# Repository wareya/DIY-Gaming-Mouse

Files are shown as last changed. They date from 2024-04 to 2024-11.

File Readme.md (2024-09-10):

# DIY Gaming Mouse

Video about why and how I made this, and what the various iterations were like: https://www.youtube.com/watch?v=h-Cdl4Vq9H4

This repository contains the code, schematic, PCB layout, and 3d model for a completely DIY gaming mouse, all designed around a Pixart PMW3360 sensor.

The firmware for this mouse uses a special debouncing algorithm that completely eliminates chatter without adding ANY latency, and eliminates bounce better than commercial mice do. Random double-clicks be gone!

None of the companies that make gaming mouse sensors sell them to consumers, including Pixart, so the sensor needs to be salvaged (or bought from a scalper, or a small business that specializes in reselling them).

<table>
  <tr>
    <td>
      
    </td>
    <td>
      
    </td>
  </tr>
  <tr>
    <td>
      opened mouse
    </td>
    <td>
      assembled mouse
    </td>
  </tr>
</table>

(The shell has a top, too, but it's turned off in this picture so you can see the PCB.)

## Features

- True zero-latency button debouncing with no glitching
- Buttons that will not develop double-clicking problems after only a few months
- Low-latency motion tracking (no smoothing)
- Completely open source (Apache 2.0 license)
- Even the hardware is open source! (except the processor and sensor)
- Ultra light-weight shell and assembly (55g in total)
- Fingertip-grip shell shape
- Extra middle mouse button
- - the button that normally controls DPI on other mice is mapped to M3
- PCB exposes extra unused pins from the rp2040 as test pads for hardware/firmware modding fun; attach your own sensors! or LEDs! whatever you want!
- Full 1000hz tracking

TODO:

- Configurable DPI (currently hardcoded at 1200)
- - To change it in the firmware code, edit the `spi_write(REG_CONFIG1, 11); // 1200 dpi` line, replacing 11 with your dpi divided by 100 minus 1, e.g. 7 for 800 dpi, 3 for 400, 15 for 1600, etc
- rebinding, macros, etc
- - can already be hardcoded atm if you're skilled at programming
- "fun" optional features like WMO-style diagonal jaggy removal or optional in-firmware acceleration, anti-smoothing (prediction), angle snapping, cinematic smoothing, etc

## Required skills

You need to be familiar with, or be able to learn quickly:

- 3d printing
- how to use a "slicer" (e.g. Cura) to convert stl models to gcode (what your 3d printer uses)
- repeatedly making test prints
- how to clean up 3d prints and remove support material from fragile prints
- basic firmware code debugging skills
- the ability to read embedded C/C++ code
- the Arduino IDE (I use 2.x, not 1.x)
- desoldering (with a hot air rework station)
- soldering (with a soldering iron)
- soldering bodge wires to existing pieces of hardware without creating solder bridges (for SROM extraction)
- comfort using a hot air rework station to soften and fix misshapen parts on 3d printed objects if they print improperly
- the ability to do all of the above without wasting tons of money or burning your home down
- familiarity with PCB printing companies and PCB assembly manufacturers (JLCPCB, PCBWay, etc)
- patience

If you cannot do all of the above, you should have someone else build this project for you, rather than building it for yourself. Or, at the very least, I can't give you support if you don't have the skills needed to make this; I'm just some random guy.

You also need:

- access to a 3d printer that you can repeatedly print test prints on until they come out right
- a hot air rework station with temperature and air flow rate control
- a soldering iron with temperature control
- hot glue device (for securing the USB cable, nothing else)
- various small tools like screwdrivers, tweezers, cleanup blades / deburring tools, etc. for various parts of the building process

## Instructions

### 3D printing the shell

This assumes you're using a filament printer. Resin printers might work too, but I have never used one.

I print with PLA filament.

Print each of the STL files in the "Case Model" directory in their natural (not default!) orientations. To repeat, some of the models have to be rotated; they're saved in the orientation they have in the mouse, not the orientation they need to have on the 3d printer's build plate.

You need to convert the stl files to gcode yourself and run various test prints because each 3d printer and filament has different requirements for layer thickness, support cutoff angle, printing speed, z seam alignment placement, etc.

Cura will complain about certain pieces (like the shell bottom) not being "water tight", but it's wrong; the watertightness check doesn't handle multiple overlapping solids properly. The models will still slice correctly and without glitches.

The thumb pieces must be rotated into the orientation where they do not need any supports. This means the small part of the thumb piece is facing up, and the long part of the switch clamp section is on the bottom.

The scroll wheel must be rotated so that the thick cylinder part is on the bottom and the thin pin part is on the top. It must be printed with supports; any type of support is fine. It should be printed at 100% speed or lower, not higher, until it gets to the pin, at which point you MUST reduce the printing speed as low as you can tolerate. On my printer, a Sovol SV06, I had to turn it down to 25% speed. If your printer doesn't allow you to change the speed mid-print, you have to print at the low speed for the entire print. This is important; you have to print it slowly, because otherwise, the pin will be misaligned with itself and the scroll wheel will be off-balance and hit the middle mouse button switch with different pressures depending on where it is in its spin cycle.

Print the scroll wheel brace as-is.

Print the shell bottom as-is. However, if you have a heated printbed or chamber, you need to wait for it to completely cool before removing it. If you remove the print while it's warm, the bottom will bend and the mouse won't sit flat. Even with mouse feet, the sensor will be at the wrong height if the bottom is bent.

Print the shell top with tree supports and a support cutoff angle between 60 and 70 degrees. Do not use "standard"/traditional/grid supports; they will be too difficult to remove, and you will probably damage the print trying to remove them. On my printer, a Sovol SV06, 67 degrees was just right. If you have poor print quality, you might need to reduce the cutoff angle down to something silly like 50 degrees. If you have to go below 50 degrees, get a better printer, or make sure you're using the right filament at the right temperature, etc.

Once the shell top is printed, you need to use a deburring tool (or other hard, sharp metal implement) to remove a small amount of material from a certain curved edge along the seam where it meets the shell bottom, on the right side of the shell (with the button pieces away from you and the "butt" part towards you). The shell will fit together without removing a small amount of material from this part of the shell top, but it'll be misaligned by around a quarter of a millimeter and the right click won't quite work right. This material has to be removed because it sags during printing, and it sags during printing because of how support bridging works; the 3d model itself is correct.

You should print each part one-by-one and check for errors each time.

The final result will be somewhat rough and rugged, but it's a functional mouse shell.

### SROM preparation

Note: The SROM is optional, but highly recommended because it contains sensor firmware bugfixes. If you can't get it, comment out the call to `srom_upload();` in `pmw3360_boot()`, and then rename the `.h` file inclusion to `#include "srom_dummy_blank.h"`, but be warned that your mouse might experience glitchy behavior like "spinout" or have generally poor tracking. For example, while writing this and testing the firmware without an SROM, I click-and-dragged a title bar on a window, and then the mouse cursor teleported 300~400 pixels to the right for no reason.

The SROM needs to be captured from an existing mouse because it's copyrighted. Give it the name `srom_3360_0x03.h`, `srom_3360_0x04.h`, or `srom_3360_0x05.h`, depending on what version it is. I poked around github and found other projects using the 3360 SROM, and this seems to be the way they decided to name their SROM header files, so I'm copying the filename from them.

Once you have the SROM, edit the `#include "srom_3360_0x05.h"` line in `3360_Mouse_pico.ino` to point to the file for your SROM.

The below is instructions on how to capture the SROM from a commercial mouse.

Capture the SROM from a commercial 3360 mouse with this code, and a standalone raspberry pi pico (not this mouse's custom PCB): https://gist.github.com/wareya/0dc3498bd80be93c47b6f79aa9164321

Note: the above SROM capturing code requires you to use the "arduino-pico" board type in the Arduino IDE. But the firmware in this repostory requires you to use the "mbed OS" rp2040 board type.

Use a breadboard to make a ripping setup equivalent to that depicted in the following image:

EspAlvz

And this post: https://github.com/wareya/DIY-Gaming-Mouse/issues/6#issuecomment-2340009477

Be very careful not to create any solder bridges between any of the pins on the 3360.

Reconnect the mouse so that it reboots and sends the SROM to the sensor again.

The output should be exactly 4094 bytes long, and the second byte should be 0x03, 0x04, or 0x05 (different versions).

Repeat the capturing process until you get the same SROM several times, just to make sure that it captured properly. To capture the SROM again, you need to reboot the mouse. This can be plugging it in to your computer again, or disconnecting and reconnecting its USB power wire, or any safe method you prefer.

The MD5 checksums of the versions of the SROM that I know about are:

```
0x03 - C64F2BDA742DD1623D6A5DC869FC5E60
0x04 - 0BCB410858FF21D091DDC497D19BC943
0x05 - 337254C54AD82C689D4B9A58D06A3CF6
```

If you have an SROM with a different version number, it might not work with this firmware. It might, but it also might not. I can't provide support for other SROM versions.

After capturing the SROM data, save it in a formatted .h file formatted as such:

```c

#define SROM_LENGTH (4094)

const uint8_t PROGMEM srom[SROM_LENGTH] =
{
0x01,
0x<version number>,
// ...
// etc
};
```

I cannot distribute the SROM in this repository, because it's copyrighted proprietary code.

Disclaimer: The above steps do not bypass any copy protection, no encryption is being broken, and copyright law is not being violated by making your own backup copy of the sensor's SROM and using it on your own device. This is fully legal in reasonable countries (like the US).

### PMW 3360 sensor salvage

The Pixart PMW3360 is not sold commercially to hobbyists or small repair shops; to get one, you have to either buy an expensive breakout board, buy it from scalpers on aliexpress (or similar), or salvage it from an existing commercial mouse. This project assumes that you're salvaging it from an existing commercial mouse, after capturing the SROM from that mouse.

You need a hot air rework station, NOT a soldering iron, to desolder and salvage the 3360 safely. If you try to use a soldering iron, even with desoldering wick and/or a desoldering pump, you are VERY likely to fail to salvage it, damaging the pins or sensor internals in the process. The 3360 is somewhat sensitive to high temperatures, so you can only heat it up for a fairly short amount of time, and desoldering the ground pin with a soldering iron will get the sensor hot enough that it might start to damage it.

The 3360 sensor's lens is usually directly mounted to the sensor by melting its clear mounting pins down onto the top of the sensor's IC package.

Take the commercial mouse's PCB, scrape off (don't break off) the top melted part of the lens's mounting posts. Then, being careful not to damage anything, remove the lens from the sensor and PCB and put it somewhere safe.

Now, put the commercial mouse's PCB upside down on a non-flammable surface, in a workspace free of any flammable material. I cannot be held responsible if you start a fire in an unsafe workspace. You have been warned!

Before continuing, you might want to cover the bottom of the sensor with paper and/or tape to prevent anything from getting inside of it. If you do this, do it in a way that doesn't create a fire hazard.

Find the bottom of the sensor's pins. To each of these pins, apply a small amount of either leaded solder (if it's all you have) or low-temperature non-leaded solder paste/gel/etc (preferred) (NOT the same thing as flux!). You want to mix your solder into the existing solder on the pins because this will lower the melting temperature of the existing solder and make it easier to desolder the chip. Use a soldering iron or hot air tool at around 600F/300C to make the two types of solder mix together. Do not physically touch the PCB or pins with the hot air tool; rely only on the air itself.

Once the solder for each pin is mixed together, pass the hot air tool over each section of pins in a circular motion until the sensor eventually, finally comes loose. At this point, use any metal tool (like metal tweezers or a screw driver) to make sure the sensor fully comes out of the PCB.

Now, use a soldering iron to clean any excess remaining solder off of the pins. If the soldering iron ends up with too much solder on it, clean it off with brass/bronze wool or similar. Be warned that, at very high temperatures, brass wool is flammable. Do not use steel wool as a subtitute, as it is even more flammable.

### PCB building and assembly

Build gerber files and drill files and all the other necessary files (BOM, pick and place, etc) that your PCB manufacturer needs to print **and assemble** the PCB. Some of the components on the PCB are very, very delicate, so unless you're a genuine expert, trying to hand-solder them is doomed.

The plugin I use to manage JLCPCB part mappings is https://github.com/Bouni/kicad-jlcpcb-tools - this is the plugin that uses the `project.db` file. However, this file is just an sqlite database, so if you want to make sure you use the right parts with another manufacturer, you can open it up with any sqlite database viewer and get the LCSC part numbers and look them up individually, then find the equivalent part for your PCBA manufacturer. However, the PCB isn't designed to require you to do this; you can look up the parts individually instead (based on their values).

Once you have your PCBs, you need the following parts to manually solder to the board:

- 6 Omron D2F-01F switches (or compatible, e.g. D2FC)
- 11mm Alps-compatible scroll wheel encoder
- salvaged PMW 3360 sensor, undamaged, pins not bent
- - 3360 sensor's lens, with mounting posts still intact
- Four dupont-compatible header pins for connecting to USB cable (optional)
- spare discrete resistors in case you messed up any of the resistor values when ordering the PCB like I did

And the following additional parts for assembly:

- USB cable, ideally with dupont-compatible connectors (you can crimp them on yourself, you don't have to buy a special cable for this)
- 3d printed shell (2 parts)
- 3d printed side buttons (2 parts)
- 3d printed scroll wheel brace (1 part)
- 3d printed scroll wheel OR salvaged scroll wheel for 11mm Alps-compatible scroll wheel encoder with the right middle-mouse-button shaft thickness
- mouse feet (salvaged or custom) with approximately 0.6mm thickness (that's zero-point-six millimeters)

The mouse feet thickness is very important, within a quarter of a millimeter! Using any other thickness of mouse feet is likely to result in poor, glitchy tracking. The PMW3360 is VERY sensitive to VERY small changes in tracking distance.

Make sure you have screws the right size to screw everything together. I recommend doing a test-fit of the shell and plain PCB with screws before doing anything else. Be careful not to overtighten the side screws; doing so can cause their mounting holes to split. The PCB is held down with two screws and the case is held together with three screws. I used salvaged screws with a major diameter (outside edge of threads) of 2mm and a minor diameter of around 1.65~1.7mm, and the holes on the case were designed around these screws, but slightly different screws will still work.

PPRKHyR

Solder the dupont-compatible header pins to the PCB, or if you have a different plan to connect the PCB to USB, do that instead. Then, connect it to your computer and make sure you can program it with the Arduino IDE. If it doesn't work, try a different copy of the PCB. Don't continue until you know that the PCB and its rp2040 processor are working properly. You should also do a test-fit of the PCB inside the 3d printed shell bottom to make sure nothing went wrong in 3d printing, and that the edge cuts and drill holes on the PCB are accurate to how they were specified in the design files.

Solder each Omron switch to the board with the plungers aligned with the outline on the silkscreen illustration. Check and double check that the switches are fully flush with the board before and while you solder them; double check that they're flush after soldering the first pin.

Test fit the PCB into the shell bottom, and without screwing anything into anything else, attach the top half of the shell and make sure that the buttons can be clicked properly and aren't clicked just by attaching the top half of the shell. If they're hard to click or they click themselves, your 3d printer has poor tolerances, and you may need to adjust the button pieces by softening them with the hot air tool and bending them slightly until they fit just right. Once you're done here, remove the PCB from the shell.

Solder the scroll wheel encoder in into the RotaryEncoder footprint on the PCB. Be very sure that it's all the way down before and while soldering it. You may need to twist the pins very slightly with a pair of needle-nose pliers to get them to fit into their holes; the holes are very narrow, on purpose, to reduce the chance of solder bridges forming between them.

firefox_2024-04-07_00-51-23

(Example photo of a 11mm Alps-compatible encoder. 11mm is the distance between the center of the rotor and the surface of the PCB, not the top to bottom of the entire encoder.)

Solder the PMW3360 sensor to the center of the PCB, making VERY, VERY sure that it's in ALL THE WAY before and while soldering it. If it's not in all the way, the PCB may not fit properly in the shell, and/or the sensor may fail to track properly. The sensor must be mounted "upside-down" relative to the rest of the board, such that the text on it is upside-down compared to the text at the top of the board. If you put the sensor in the wrong way, it will look uncentered; if you put it in the right way (upside-down), it will look centered. If you get the wrong, the sensor might fry itself when you turn the mouse on, and the lens might not even fit against the sensor through the PCB.

Attach the lens to the sensor on the underside of the PCB. Then, slot the PCB into the bottom shell and make sure it fully fits all the way down.

If, at this point, you connect the mouse to USB again and check what it says in the Arduino IDE's "Serial Logger" when the mouse boots, and the SROM's ID is a value other than zero or 0xFF, the sensor is working properly. If it's working properly but still doesn't track, double check the value of the LED resistor; that's the component closest to the "U10" silkscreen text, also near four diodes arranged in a rectangle (not in a row). The resistor value should be 39 ohms, or something very close like 40. If the resistor value is wrong, you have to desolder it and bodge on 40 ohms worth of discrete resistors (I personally use two 20 ohm resistors in series). WARNING: Using too few ohms will permanently damage the sensor's LED and make the sensor useless.

Remove the PCB and fit the side button thumb pieces to their switches. This is difficult and should feel like you're almost going to break the thumb pieces, but not like you're definitely going to break them. The long piece of the switch brace should wrap around the "inside" of the switches (towards the other side button switch), not the "outside". To get the thumb pieces around the switches, first fit the "hook" to the bottom around the edge of the PCB, slightly offset from the switch, and rotate the thumb piece down so that the far end of its brace hits the top of the switch. Move it as far from the switch as you comfortably can, so that it doesn't have to bend too much to slide down past the top and around the other side of the switch. Once that happens, slide it towards the switch so that the small hook piece at the end of the brace fully wraps around the other corner of the switch. Repeat this for the other switch's thumb piece.

firefox_2024-04-08_01-20-12 firefox_2024-04-08_01-20-14 firefox_2024-04-08_01-20-17 firefox_2024-04-08_01-20-19

Above is a visual image series depicting the process for mounting the thumb button pieces. It's OK if they crack or break while attempting to fit them; they will still fit and work, just be slightly less snug than they're supposed to be.

Fit scroll wheel brace around the middle mouse button (near the right mouse button), with the spikes towards the "inside" of the mouse and away from the middle mouse button. Now fit the scroll wheel and make sure it's snug and properly balanced. If it's not, you'll need to reprint it.

Put the PCB back into the shell bottom and make sure it's still snug. Route the USB cable behind the support post in the back of the case (it has a screw hole in it) and around the right side of the PCB (NOT the left side), hugging the right side of the right mouse button, and then feed it out through the slot in the front. Use hot glue to secure the USB cable to that front slot. Make sure that it points relatively straight out the front when you hot glue it down.

Plug it in, compile and upload the firmware from the Arduino IDE, and make sure everything works. If it does, you're done! Just re-screw everything together. Be careful not to overtighten the side screws; doing so can cause their mounting holes to split.

## License

3360_Mouse_pico.ino, the main file of this project, is released under the Apache License, version 2.0.

relmouse_16.h is based on files from mbed OS, also licensed under the Apache License, version 2.0. https://github.com/arduino/ArduinoCore-mbed

The hardware design files (under "Case Model" and "KiCad schematic + PCB") are licensed under the SolderpadLicense, version 2.1, as follows:

```
Copyright 2024 wareya
SPDX-License-Identifier: Apache-2.0 WITH SHL-2.1

Licensed under the Solderpad Hardware License v 2.1 (the “License”); you may not use this file except in compliance with the License, or, at your option, the Apache License version 2.0. You may obtain a copy of the License at

https://solderpad.org/licenses/SHL-2.1/

Unless required by applicable law or agreed to in writing, any work distributed under the License is distributed on an “AS IS” BASIS, WITHOUT WARRANTIES OR CONDITIONS OF ANY KIND, either express or implied. See the License for the specific language governing permissions and limitations under the License.
```

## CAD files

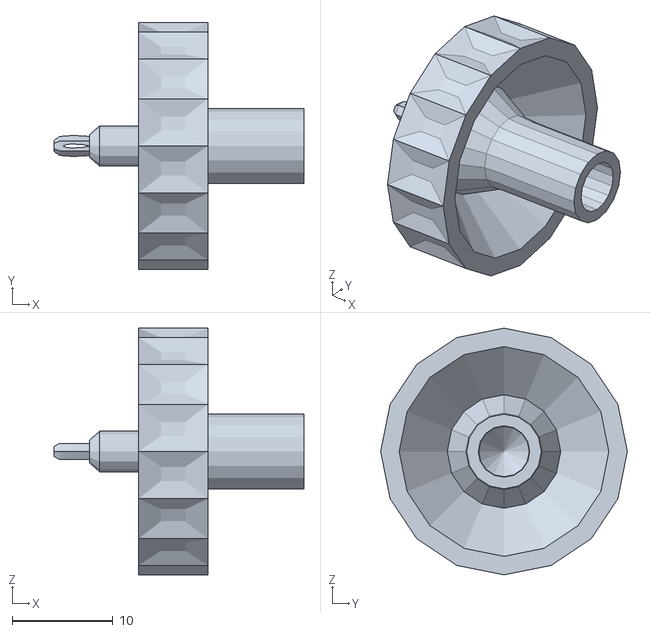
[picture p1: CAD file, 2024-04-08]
Case Model/mouse shell progress pico 2 wheel.stl
24.8 x 24.5 x 24.5

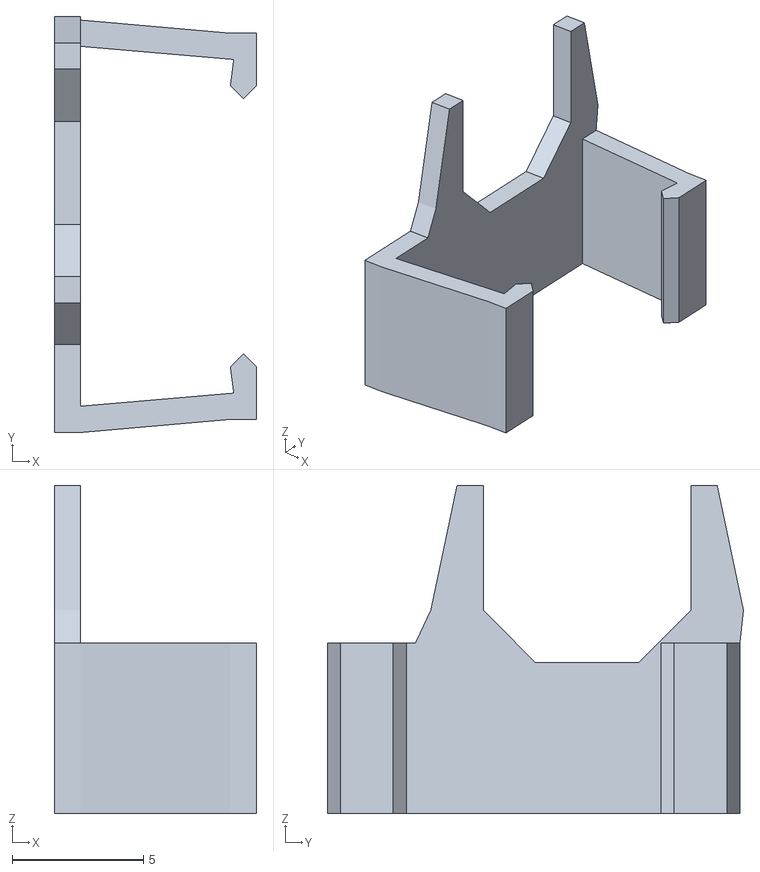
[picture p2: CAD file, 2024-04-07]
Case Model/mouse shell progress pico 2 wheel brace.stl
7.70 x 15.8 x 12.5

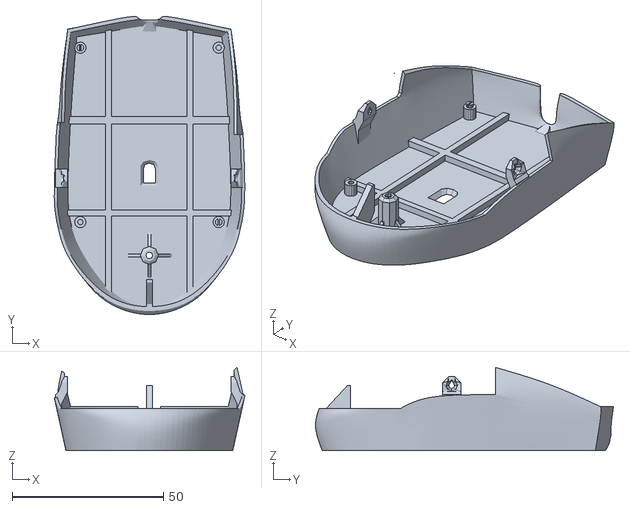
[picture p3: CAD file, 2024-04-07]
Case Model/mouse shell progress pico 2 bottom.stl
63.0 x 98.5 x 27.5

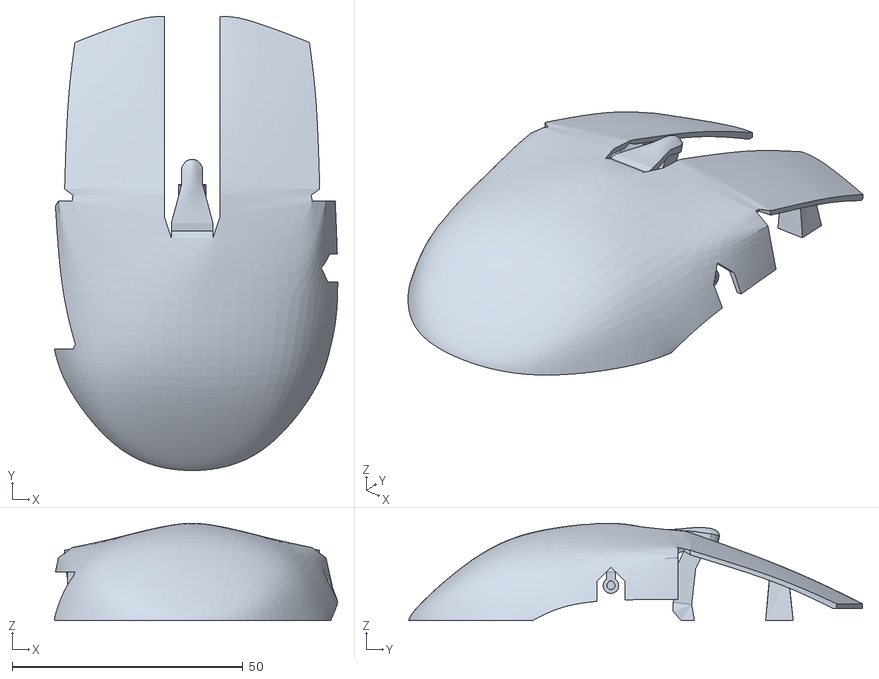
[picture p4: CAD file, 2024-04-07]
Case Model/mouse shell progress pico 2 top.stl
61.4 x 98.4 x 21.1

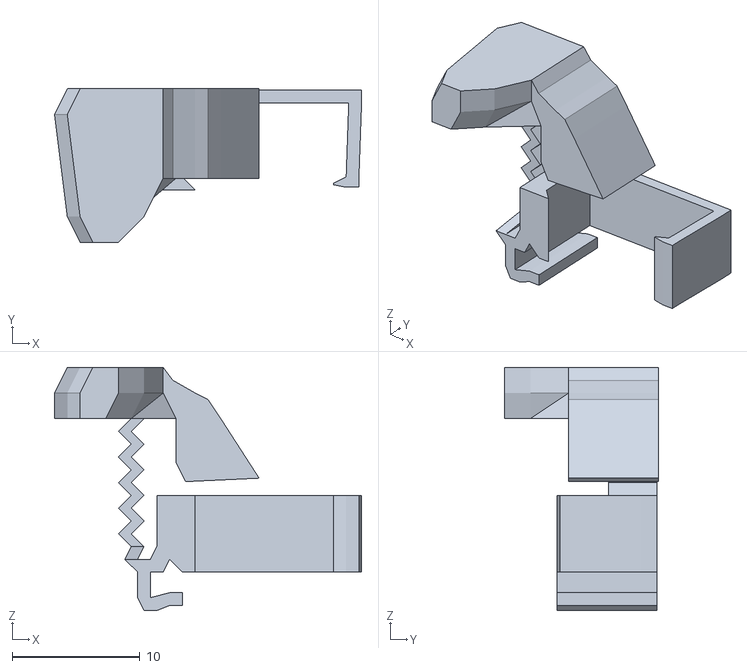
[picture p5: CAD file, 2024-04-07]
Case Model/mouse shell progress pico 2 thumb b.stl
24.0 x 12.0 x 19.0

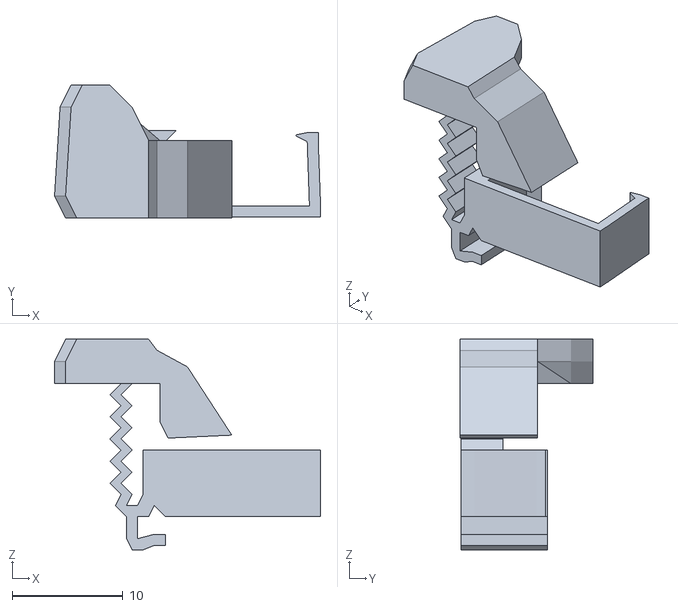
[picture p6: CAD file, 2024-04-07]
Case Model/mouse shell progress pico 2 thumb a.stl
24.0 x 12.0 x 19.0

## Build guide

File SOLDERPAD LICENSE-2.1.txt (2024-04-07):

Solderpad Hardware License v2.1

This license operates as a wraparound license to the Apache License
Version 2.0 (the “Apache License”) and incorporates the terms and
conditions of the Apache License (which can be found here:
http://apache.org/licenses/LICENSE-2.0), with the following additions
and modifications. It must be read in conjunction with the Apache
License. Section 1 below modifies definitions and terminology in the
Apache License and Section 2 below replaces Section 2 of the Apache
License. The Appendix replaces the Appendix in the Apache License.
You may, at your option, choose to treat any Work released under this
license as released under the Apache License (thus ignoring all
sections written below entirely).

1. Terminology in the Apache License is supplemented or modified as
follows:

“Authorship”: any reference to ‘authorship’ shall be taken to
 read “authorship or design”.

“Copyright owner”: any reference to ‘copyright owner’ shall be taken
 to read “Rights owner”.

“Copyright statement”: the reference to ‘copyright statement’ shall be
 taken to read ‘copyright or other statement pertaining to Rights’.

The following new definition shall be added to the Definitions section
of the Apache License:

“Rights” means copyright and any similar right including design right
 (whether registered or unregistered), rights in semiconductor
 topographies (mask works) and database rights (but excluding Patents
 and Trademarks).

The following definitions shall replace the corresponding definitions
in the Apache License:

“License” shall mean this Solderpad Hardware License version 2.1,
 being the terms and conditions for use, manufacture, instantiation,
 adaptation, reproduction, and distribution as defined by Sections 1
 through 9 of this document.

“Licensor” shall mean the owner of the Rights or entity authorized by
 the owner of the Rights that is granting the License.

“Derivative Works” shall mean any work, whether in Source or Object
 form, that is based on (or derived from) the Work and for which the
 editorial revisions, annotations, elaborations, or other
 modifications represent, as a whole, an original work of authorship
 or design. For the purposes of this License, Derivative Works shall
 not include works that remain reversibly separable from, or merely
 link (or bind by name) or physically connect to or interoperate with
 the Work and Derivative Works thereof.

“Object” form shall mean any form resulting from mechanical
 transformation or translation of a Source form or the application of
 a Source form to physical material, including but not limited to
 compiled object code, generated documentation, the instantiation of
 a hardware design or physical object or material and conversions to
 other media types, including intermediate forms such as bytecodes,
 FPGA bitstreams, moulds, artwork and semiconductor topographies
 (mask works).

“Source” form shall mean the preferred form for making modifications,
 including but not limited to source code, net lists, board layouts,
 CAD files, documentation source, and configuration files.

“Work” shall mean the work of authorship or design, whether in Source
 or Object form, made available under the License, as indicated by a
 notice relating to Rights that is included in or attached to the
 work (an example is provided in the Appendix below).

2. Grant of License. Subject to the terms and conditions of this
License, each Contributor hereby grants to You a perpetual,
worldwide, non-exclusive, no-charge, royalty-free, irrevocable
license under the Rights to reproduce, prepare Derivative Works of,
make, adapt, repair, publicly display, publicly perform, sublicense,
and distribute the Work and such Derivative Works in Source or Object
form and do anything in relation to the Work as if the Rights did not
exist.

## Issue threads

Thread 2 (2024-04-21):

Use optical switches [suggestion]

raszpl, 2024-04-21:
No debouncing required, infinite click lifetime, only limit is LED lifetime.
Buttons $2 [D2FP-FN2](https://www.digikey.com/en/products/detail/omron-electronics-inc-emc-div/D2FP-FN2/21410416)
Can also design your own PCB optical beam sensorts and have 3d printed button move slit into the path of light. Razer and TTC do a plastic shell with a lever going into PCB light sensors, here a 3d cutout of TTC http://en.ttc9.com/product/50.html fancy animation https://www.linkedin.com/posts/jeffrey-hu-8a5559101_ttc-optical-micro-switch-for-mouse-with-a-activity-6762816336910532608-CXmb

Wheel https://cdn4.explainthatstuff.com/how-ball-mouse-works.jpg Would need to hunt right size with good availability. Something like:
$3 https://www.ebay.com/itm/305117600440 [Photoelectric Speed Sensor Encoder Coded Disc Code Wheel For Freescale Smart gs]
$4 https://www.ebay.com/itm/144130543656 [HC-020K Photoelectric Rotational Speed Sensor with Encoder Code Disc Code WheelH]

Mechanical encoders are just a cost optimization, part of Logitech plan to turn mouse business into Recurring Revenue stream with everyone replacing their mice once a year.

I put optical switches into my Steelseries to make it reliable. Im still looking for perfect scroll wheel mechanism. Especially click relying on rotating shaft directly pressing on the microswitch is a big fail, delivers uneven often squeaky rotation.
Personally I went reusing components route by buying defective, most often "double click", top shelf mice for peanuts (~$1 + shipping) and mixing/matching parts.

wareya, 2024-04-22:
Optical switches are something I'm totally down for looking into, but it might be quite a while before I research them. My backlog is stuffed.

For the 3d printed light blocking idea, I'm afraid filament 3d printers aren't quite precise enough for it. Mouse switches have to be precise to within something like 0.05mm, but the standard nozzle thickness on 3d printers is 0.4mm.

Optical encoders actually have some challenges of their own. Because they're exposed to open air, it's easy for them to gunk up and start skipping or glitching on specific sections of the rotation. But at the same time, they're easier to clean non-destructively and keep working for a very long time. IMO, they're a tradeoff.

wareya, 2024-04-22:
PS: My personal solution to M3/middle click button problems is to make the dpi button a second middle mouse button.

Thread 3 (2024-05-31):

Question: Height of PCB?

C4illin, 2024-05-31:
What height should the PCB be? 1.6mm?

wareya, 2024-05-31:
Yep, 1.6mm standard!

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

C4illin, 2024-05-31:
Thank you!

Do you have any JLCPCB part list? The project.db seems to be unpopulated

wareya, 2024-05-31:
It seems to contain the right data for me:

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

The plugin that uses project.db is https://github.com/Bouni/kicad-jlcpcb-tools

C4illin, 2024-06-01:
Ohh didn't know about that plugin. It was only missing R40 but that one was easy to find :) Thanks for the help!

wareya, 2024-06-01:
Make sure you don't do what I did and accidentally get a 3.9k ohm resistor instead of a 39 ohm one! The 39 ohm ones don't show up in the 'Basic' catalog.

C4illin, 2024-06-01:
Yeah if it was something I learned from the video it was that 😄
I actually used that frame in the video to try matching so I got all component right, before asking here :)

I was thinking of taking the C137630 from extended catalog.

wareya, 2024-06-01:
Yep, the C137630 should work!

C4illin, 2024-06-01:
Thanks for all the help!

C4illin, 2024-06-02:
Hello, in the DB it says to use C22775 for R3, R4 but C22775 is 100 ohm and not 27 ohm as specified, what is correct?

wareya, 2024-06-02:
Those would be the USB data line impedance control resistors. I think putting in 100 ohm resistors is probably a mistake on my part.

Their exact resistance probably doesn't matter too much. 27.4 ohms is the value suggested/specified by the rp2040 hardware design docs. I would expect anything between 10 and 50 to work in practice. The target resistance for the entire data line according to the usb spec is 90 ohms, and real usb parent devices are more generous than that in practice.

I'll amend the part selection and double check everything again when I have a few spare hours.

C4illin, 2024-06-02:
100 ohm is much cheaper on jlcpcb ;)

wareya, 2024-06-02:
Looks like I did indeed end up using 100 ohm resistors (01A):

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

So yeah, should still work! Unless you have a particularly picky machine.

Closed 2024-06-01.

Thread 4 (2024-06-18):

Recreation

SpillAway, 2024-06-18:
Hey Wareya,

So basically I'm working with a team of friends trying to recreate your mouse. We have the PCB which we got from PCB Way. I was wondering if you could walk us through the process. You can contact me by email at: pn52tfzvy@mozmail.com.

Thank You
Kind Regards
Spill_Away

misel228, 2024-06-18:
There's a very detailed list of things you need to know be capable of before this endevour, right on the start page: https://github.com/wareya/DIY-Gaming-Mouse

Read this and start working on it. When you get stuck, try to explain what exactly is happening *and* what you expect instead.

When asking questions, try to follow this guide: https://stackoverflow.com/help/how-to-ask

Good luck

wareya, 2024-06-18:
The above post is right. The best place to start with this kind of activity is by trying and getting it wrong, and then figuring out how to fix what went wrong. If you run into any specific problems, feel free to ask! I'll be happy to help. The more specific you are and the fewer back-and-forths it takes, the better my help will be.

SpillAway, 2024-06-26:
We have a **$300** budget and we need to make 3. So we can't fail and then expect to do it again.

wareya, 2024-06-26:
The shell parts weren't designed in traditional CAD software, they were designed in blender. The .blend file is the source file. There are no STEP source files.

A 300 dollar budget sounds like plenty to make a few mistakes, as long as that budget doesn't include getting the tools needed to build and assemble everything (3d printer, etc).

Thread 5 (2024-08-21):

Tuning mouse report rate for optimal VSync frame pacing

fuweichin, 2024-08-21:
To avoid pointer movement stuttering when coalescing HID input messages as VSync-aligned pointer events, it is necessary to design a mouse report rate (or say sampling rate, sometimes) which is integral multiple of display refresh rate.

So, for the common refresh rates 60Hz/120Hz, it's neccesary to use a report rate like 120Hz to keep VSync frames even in terms of pointer movement.

Yet I cannot find a mouse which is optimized for VSync frame pacing, that's why I'm interested in DIY/open-source mouse.

Why integral multiple? Here are some testing results with [Pointer Movement Timing Analyzer](https://beta.tourofdreamland.net/device-tests/hid/pointer-movement-timing-analyzer/):

Figure1: using 119Hz report rate with 60Hz refresh rate MAY cause 1 jumpy frame per second
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

Figure2: using 125Hz report rate with 60Hz refresh rate MAY cause 5 jumpy frames per second
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

Apple continuously optimizes report rates for VSync frame pacing, and now only leaves its Magic Mouse and Magic Trackpad behind.

Table1: Apple Products HID Sampling Rate

| Device                 | Pointer Type   | Sampling Rate | Refresh Rate |
| ---------------------- | -------------- | ------------- | ------------ |
| iPhone 13 Pro          | touchscreen    | 240Hz         | 120Hz        |
| iPhone 12              | touchscreen    | 120Hz         | 60Hz         |
| iPad Pro 12.9" 2nd gen | touchscreen    | 120Hz         | 120Hz        |
| Apple Pencil           | pen            | 240Hz         |              |
| MacBook Pro M1         | mouse/touchpad | 120Hz         | 120Hz        |
| Magic Mouse            | mouse          | 90Hz          |              |
| Magic Trackpad         | mouse/touchpad | 90Hz          |              |

wareya, 2024-08-21:
USB 2.x HID report rates unfortunately need to be millisecond-aligned, which means that the only options between 125hz and 1000hz are as follows:

```
125hz (8ms)
~142.8hz (7ms)
~166.6hz (6ms)
200hz (5ms)
250hz (4ms)
~333.3hz (3ms)
500hz (2ms)
1000hz (1ms)
```

Any report rates for a USB HID device between these is, in reality, switching back and forth between similar rates to give an average of the measured rate.

The easiest way to avoid input device movement microstutter is to use as high of a report rate as possible. This is one of the reasons that gaming mouse firmware (including this repo) has decided on 1000hz (sometimes 500hz) as the standard. Doing this also minimizes input latency. Modern office mice still use 125hz, but they're just being weird/bad.

Some modern mice are capable of using even higher sampling rates, like 8000hz, over higher-speed versions of USB. For these mice, more sample rates are possible, but for input latency reasons, it's still best to use the highest sample rate that can be stably maintained. The rp2040 isn't capable of these even higher-speed versions of USB.

Also, the 3060 sensor in this mouse has a sampling rate of its own (something in the dozens of khz), so at some point down the signal chain, there's always going to be a small amount of microstutter.

If you're on linux, you can sometimes override USB device polling rate: https://wiki.archlinux.org/title/Mouse_polling_rate#Set_polling_interval

fuweichin, 2024-08-21:
Mouse DIY players can take the lead in improving mouse VSync frame pacing even via some just-works solution, as a proof of concept to deliver unique value to the industry, e.g. use 8000Hz (0.125ms interval) sampling rate sensor then downsample to a of 120Hz (8.333...ms interval) report rate, e.g. ~119.4Hz (8.375ms interval), which is better than 125Hz in terms of VSync frame pacing, better than 1000Hz in terms of energy efficiency.

That shouldn’t be something only-Apple-can-do.

Indeed, 1000Hz report rate can reduce VSync pointer movement microstutter,
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

but is at the cost of higher CPU usage, e.g. moving 1000Hz mouse over empty area causes 10% CPU usage(i7-7920HQ, Windows 10), on Windows 10 desktop that causes extra 10% CPU usage if “Show desktop icons” is checked, which means more heat and fan noise.
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

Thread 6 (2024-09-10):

More details needed about ripping setup

Deozaan, 2024-09-10:
Thanks for the video and the open repository. I'm trying to follow along but a simple photograph of the ripping setup isn't adequate for me. The angle is not great and it is difficult for me to understand what needs to be connected to what.

Would it be possible to get a written description of the setup? Which colored wires in the photo are connecting to which pins on the Pico? What type of resistor is on the breadboard, and which pins on the Pico is it connected to? And are there any labels on the PWM sensor/chip to make it explicit which ones are being connected to?

I'd really prefer not to fry any of my components so I'd like to be able to triple check that everything is as it should be before attempting this. Thank you!

wareya, 2024-09-10:
Following this image as reference: https://i.imgur.com/EspAlvz.jpeg

The sensor has the text "A23" on the "bottom" edge, i.e. towards where the wrist would be when holding the mouse, the top of the photo. However, the sensor is usually mounted upside-down, so this is actually the top.

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
(https://i.imgur.com/zneMFco.png)

This illustration shows the pin numbers for the sensor and which pin numbers need to be tapped to record the SPI message.

- GPIO16 need to be connected to pin 10
- GPIO17 need to be connected to pin 11
- GPIO18 need to be connected to pin 12
- GPIO19 need to be connected to pin 13
- GPIO19 needs to be pulled high to a 3.3 volt source with a 1 ***mega***-ohm resistor. The exact value is not important but it should be very large. 10kohms for example would be too low. 100kohm to 10mega-ohms is probably a safe range.

Deozaan, 2024-09-10:
Thank you very much for the clear and detailed explanation.

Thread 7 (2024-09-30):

Gerber files for PCB

ElPoncholino, 2024-09-30:
Hi !

Here is my journey on this project. My questions are in bold. If you're not interrested of the rest, it will be easier to follow it.
I launch myself on this project. I need a new mouse for the laptop I use for work, and why don't create it instead of buying it ?

First of all, I need an ergonomic mouse, for all the reasons possible to use it everyday for at least 8 hours.
So I redesign a bit the mouse in order to add some curves which created more contact surfaces with my hand.
To not complicate the assembly, I kept the place of all components, just changed the top and bottom body.

Here are some pictures :
![Uploading WhatsApp Image 2024-09-27 at 17.52.35.jpeg…]()
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

With the general design in mind, I planned the printing. To thing is offered to me, filament or resin.
I will try the top body in resin to see if the elasticity of the click could work. But honestly I don't bet on it. I will keep you inform about that. For the bottom, it will be in filament because of the size, and every other piece will be in resin.

Then comes the sensor.
I've bought directly a sensor because I've not have an hot air station.
I take the SROM but something is stange in it. It has a "#include ..." in it which seems to be a library called.
**Can i removed this line ? Is it normal to have it ? I've not the files which compose the library, so could it work ?**
For the rest of the SROM, it looks like the dummy one, but with letters and numbers instead of zero.

About the PCB :
I've already made an order on jlcpcb, but for that I had the gerber files.
Here I don't find them. I download kiCad but couldn't export the gerber files in order to directly make them with the components on it.
**Could you give the gerber files you used for your order ?**

I will try to continue on this project by myself and give some feedback and final pictures.

Thanks for reading me !

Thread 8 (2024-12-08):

Wireless plans?

bam80, 2024-12-08:

wareya, 2024-12-08:
currently doing the planning 👍
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

bam80, 2024-12-08:
Hi Alexander,
that's great to hear!

I'm interested with the firmware, did you considered one?
I found another project (no wireless so far) based on QMK:
https://github.com/qmk/qmk_firmware/tree/master/keyboards/ploopyco

But maybe ZMK is a better suit for wireless?
What do you think?

wareya, 2024-12-08:
I'm going to run another version of my own custom firmware so that I can micromanage power delivery and sleep states.

bam80, 2024-12-08:
Good luck!

willwaush, 2025-01-19:
Are you planning on using the PicoW for wireless connectivity?

Would be glad to help in terms of electronics if needed. Can't wait for this project to get the wireless functionality!

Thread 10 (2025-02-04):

BOM missing part R39

BrendanSiche, 2025-02-04:
Hello,

I would like to order the pcb, I generated the files using kicad and the jlcpcb plugin
I'm not sure about the last row tho.
The value of R39 is R40 in the comments, is that just a cosmetic thing or have the row been mismatched somehow ?
I tried looking for the part itself(R_0603_1608Metric) but everything seems to be out of stock

Does anyone know what that last row should be before I order the pcb ?

additional question, but I know the video build log had an issue with a wrong value resistor beeing ordered (3.9k ohm instead of 39) is it fixed in the repo's file ?

Thanks !

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

wareya, 2025-02-04:
40 ohms is acceptable and close enough, I think I had problems finding an R39 at the time and tried replacing it with an R40, but somehow confused myself and ended up with a 3.9k. I don't remember whether I fixed it in the repo yet or not.

See also: https://github.com/wareya/DIY-Gaming-Mouse/issues/3#issuecomment-2143805471

BrendanSiche, 2025-02-04:
Thanks !
I chose C137630 for the missing part, it seems to be good at 39 ohm, ordering the pcb now, I hope it'll work out okay !

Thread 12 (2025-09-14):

Issue with SROM ripping code.

josht000, 2025-09-14:
I have the RP2040 all connected as you and others shared. However, I had to modify the code just a little to get to compile and such. I'm not getting any output in the Serial Monitor and want to veryify a few things in the code. The [gist](https://gist.github.com/wareya/0dc3498bd80be93c47b6f79aa9164321) you point us to says, "long SPI message recorder - rasberry pi pico (rp2040), arduino IDE .ino file (C++)" at the top of the page. Ok Great, so it's an Arduino IDE project. Well then why does it include  #include <pico/stdlib.h>??? Everyone says you shouldn't do this and indeed I get file not found errors. I had to use #include <Arduino.h> instead and replace Serial.printf with printf(). Could that be causing me issues by not seeing output on the Serial Monitor?? What did you do?

Thanks for any help and my PCB's are already in the states on their way to me :)

josht000, 2025-09-14:
I know those solder globs are **sus,** but there's no connection there - _probably_.
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

wareya, 2025-09-14:
It's strange that you needed to change the includes, and it's probably the reason that it's not printing anything, yeah. Which board target configuration were you using?

josht000, 2025-09-14:
RP2040 Pico 1 using the Arduino IDE and the MBed OS RP2040 Boards, by Arduino, version 4.4.1 installed.

What version did you use to program?

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

josht000, 2025-09-14:
@wareya v4.4.1?

josht000, 2025-09-16:
Ok, my options look the same as yours and the code is essentially running fine, but still not able to get the full 4096 bytes out. Would you mind sharing where you got your donor mouse?

wareya, 2025-09-16:
It was "Plugable"'s pmw3360 mouse and I bought it from amazon, but it's no longer for sale unfortunately.

If you don't specifically need to rip the SROM code yourself, you can dummy out the SROM uploading parts of the firmware and the mouse should still work; it'll just be more liklely to glitch out on incompatible tracking surfaces.

It might somehow be a problem with wire length or solder connection quality, but it would be really weird if this was the problem. Maybe I forgot about a buffer to ground or live voltage or something...

Deozaan, 2025-09-16:
I also had trouble dumping/ripping the SROM in full when I attempted this about a year ago. I never got it to work in full, all at once. I kept getting fragments of varying lengths, always different, but with sections of sequences of numbers that matched other fragments from other attempts.

After many attempts I was eventually able to piece the fragments together into a full 4096 byte file. I was able to verify that I had a match to a known-good SROM file by finding other DIY mouse repositories which included 4096 byte SROM files for this sensor and comparing them to what I had pieced together.

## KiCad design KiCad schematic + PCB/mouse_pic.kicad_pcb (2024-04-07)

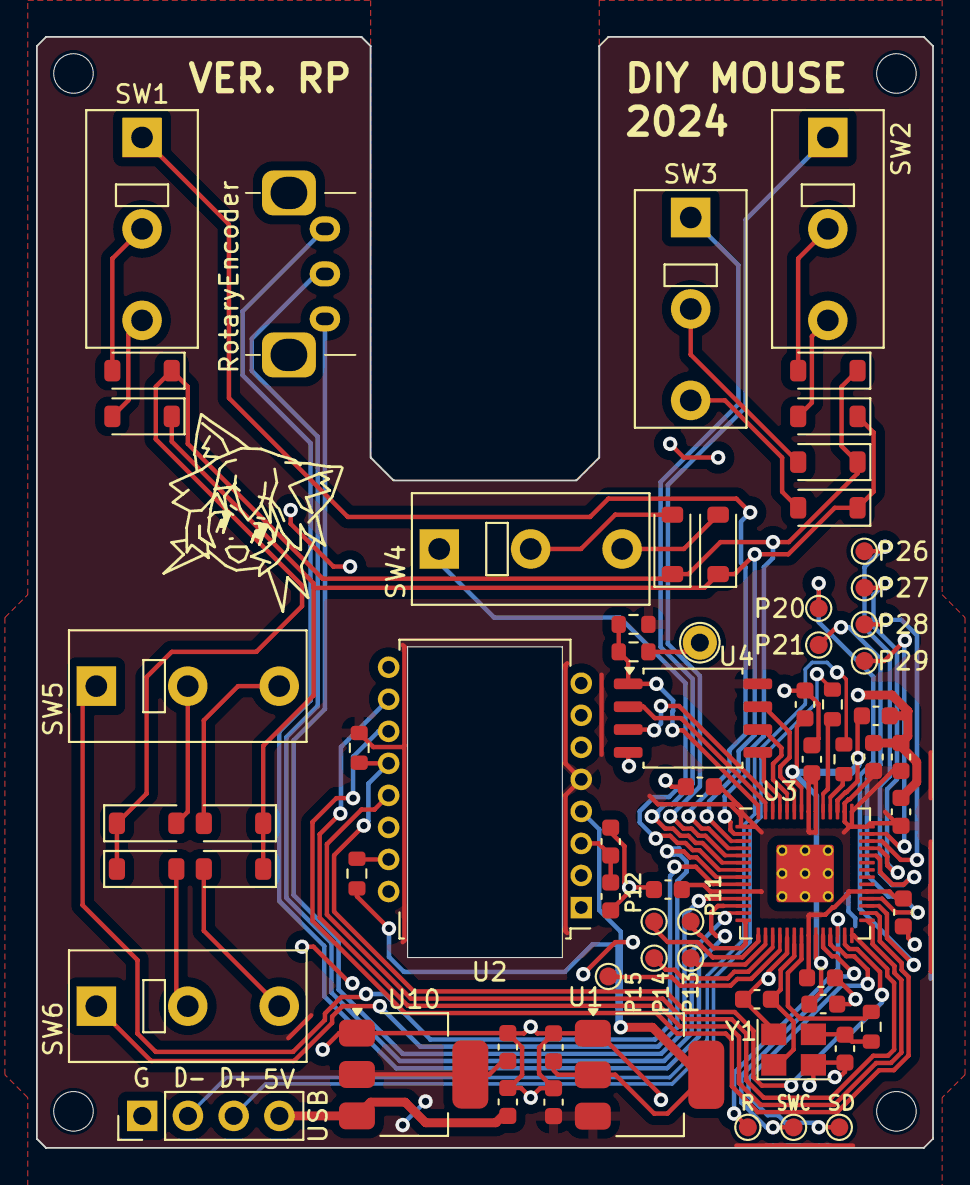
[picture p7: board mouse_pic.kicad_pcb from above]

Board: 2 copper layers, 49.8 x 61.7 mm, 67 parts (0 on the bottom side), 62 nets.

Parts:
C1, C2: 10uF; C_0603_1608Metric
C3: 100nF; C_0603_1608Metric
C4: 4.7uF; C_0603_1608Metric
C6, C7, C9, C11, C12, C13, C14, C15, C500: 100n; C_0603_1608Metric
C8, C10: 1u; C_0603_1608Metric
C100, C400: 10u; C_0603_1608Metric
C200, C300: 15p; C_0603_1608Metric
D1, D2, D3, D4, D5, D6, D7, D8, D9, D10, D11, D12: D; D_SOD-123
Encoder1: RotaryEncoder; Alps-EC10E1220501
P11, P12, P13, P14, P15, P20, P21, P26, P27, P28, P29, P30, P31, P32: TestPoint; TestPoint_Pad_D1.0mm
R1: 10K; R_0603_1608Metric
R3, R4: 27; R_0603_1608Metric
R40: R39; R_0603_1608Metric
R100, R500: 1k; R_0603_1608Metric
R200: 10k; R_0603_1608Metric
SW1, SW2, SW3, SW4, SW5, SW6: SW_SPDT; SW_Tactile_SPDT_Omron_D2F
U1: LM1117-1.8V; SOT-223-3_TabPin2
U2: PMW3360DM-T2QU; PixArt_PDIP-16_10.9x16.2mm_P1.78mm
U3: RP2040; RP2040-QFN-56
U4: W25Q32JVSS; SOIC-8_5.275x5.275mm_P1.27mm
U10: NCP1117-3.3_SOT223; SOT-223-3_TabPin2
USB1: USB; PinHeader_1x04_P2.54mm_Vertical
USB_BOOT1: Conn_01x01_Socket; TestPoint_THTPad_D2.0mm_Drill1.0mm_Edit
Y1: ABM8-272-T3; Crystal_SMD_3225-4Pin_3.2x2.5mm

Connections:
+1V1: C6.1, C7.1, C8.1, U3.23 (DVDD), U3.45 (VREG_VOUT), U3.50 (DVDD)
+3V3: C1.1, C9.1, C10.1, C11.1, C12.1, C13.1, C14.1, C15.1, C400.1, C500.1, R1.2, R200.1, U1.3 (VI), U2.5 (VDDIO), U3.1 (IOVDD), U3.10 (IOVDD), U3.22 (IOVDD), U3.33 (IOVDD), U3.42 (IOVDD), U3.43 (ADC_AVDD), U3.44 (VREG_IN), U3.48 (USB_VDD), U3.49 (IOVDD), U4.8 (VCC), U10.2 (VO)
/3360LED: R40.1, U2.15 (LED_P)
/ENC_A: Encoder1.A, U3.11 (GPIO8)
/ENC_B: Encoder1.B, U3.13 (GPIO10)
/ENC_C: Encoder1.C, U3.12 (GPIO9)
/GPIO0: D1.1 (K), D3.1 (K), D5.1 (K), D7.1 (K), D9.1 (K), D11.1 (K), U3.2 (GPIO0)
/GPIO1: D2.1 (K), D4.1 (K), D6.1 (K), D8.1 (K), D10.1 (K), D12.1 (K), U3.3 (GPIO1)
/GPIO2: SW1.2 (B), U3.4 (GPIO2)
/GPIO3: SW2.2 (B), U3.5 (GPIO3)
/GPIO4: SW3.2 (B), U3.6 (GPIO4)
/GPIO5: SW4.2 (B), U3.7 (GPIO5)
/GPIO6: SW6.2 (B), U3.8 (GPIO6)
/GPIO7: SW5.2 (B), U3.9 (GPIO7)
/GPIO11: P11.1, U3.14 (GPIO11)
/GPIO12: P12.1, U3.15 (GPIO12)
/GPIO13: P13.1, U3.16 (GPIO13)
/GPIO14: P14.1, U3.17 (GPIO14)
/GPIO15: P15.1, U3.18 (GPIO15)
/GPIO16: R1.1, U2.12 (MISO), U3.27 (GPIO16)
/GPIO17: U2.13 (NCS), U3.28 (GPIO17)
/GPIO18: U2.10 (SCLK), U3.29 (GPIO18)
/GPIO19: U2.11 (MOSI), U3.30 (GPIO19)
/GPIO20: P20.1, U3.31 (GPIO20)
/GPIO21: P21.1, U3.32 (GPIO21)
/GPIO26_ADC0: P26.1, U3.38 (GPIO26_ADC0)
/GPIO27_ADC1: P27.1, U3.39 (GPIO27_ADC1)
/GPIO28_ADC2: P28.1, U3.40 (GPIO28_ADC2)
/GPIO29_ADC3: P29.1, U3.41 (GPIO29_ADC3)
/QSPI_SCLK: U3.52 (QSPI_SCLK), U4.6 (CLK)
/QSPI_SD0: U3.53 (QSPI_SD0), U4.5 (DI(IO0))
/QSPI_SD1: U3.55 (QSPI_SD1), U4.2 (DO(IO1))
/QSPI_SD2: U3.54 (QSPI_SD2), U4.3 (IO2)
/QSPI_SD3: U3.51 (QSPI_SD3), U4.7 (IO3)
/QSPI_SS: R100.1, R200.2, U3.56 (QSPI_SS), U4.1 (~CS)
/RUN: P30.1, U3.26 (RUN)
/SWCLK: P31.1, U3.24 (SWCLK)
/SWD: P32.1, U3.25 (SWD)
/USBD+: R3.1, USB1.3
/USBD-: R4.1, USB1.2
/V2: C2.1, R40.2, U1.2 (VO), U2.4 (VDD)
/VDDPIX: C3.1, C4.1, U2.3 (VDDPIX)
/XIN: C200.1, U3.20 (XIN), Y1.1
/XOUT: R500.1, U3.21 (XOUT)
/~USB_BOOT: R100.2, USB_BOOT1.1
GND: C1.2, C2.2, C3.2, C4.2, C6.2, C7.2, C8.2, C9.2, C10.2, C11.2, C12.2, C13.2, C14.2, C15.2, C100.2, C200.2, C300.2, C400.2, C500.2, U1.1 (GND), U2.8 (GND), U3.19 (TESTEN), U3.57 (GND), U4.4 (GND), U10.1 (GND), USB1.1, Y1.2, Y1.4
unnamed: C300.1, R500.2, Y1.3
unnamed: D1.2 (A), SW1.1 (A)
unnamed: D2.2 (A), SW1.3 (C)
unnamed: D3.2 (A), SW2.1 (A)
unnamed: D4.2 (A), SW2.3 (C)
unnamed: D5.2 (A), SW3.1 (A)
unnamed: D6.2 (A), SW3.3 (C)
unnamed: D7.2 (A), SW4.1 (A)
unnamed: D8.2 (A), SW4.3 (C)
unnamed: D9.2 (A), SW5.1 (A)
unnamed: D10.2 (A), SW5.3 (C)
unnamed: D11.2 (A), SW6.1 (A)
unnamed: D12.2 (A), SW6.3 (C)
unnamed: R4.2, U3.46 (USB_DM)
unnamed: R3.2, U3.47 (USB_DP)
VBUS: C100.1, U10.3 (VI), USB1.4

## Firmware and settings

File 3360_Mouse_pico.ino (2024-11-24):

/*
 * Copyright (c) 2024, wareya
 * SPDX-License-Identifier: Apache-2.0
 *
 * Licensed under the Apache License, Version 2.0 (the "License");
 * you may not use this file except in compliance with the License.
 * You may obtain a copy of the License at
 *
 *     http://www.apache.org/licenses/LICENSE-2.0
 *
 * Unless required by applicable law or agreed to in writing, software
 * distributed under the License is distributed on an "AS IS" BASIS,
 * WITHOUT WARRANTIES OR CONDITIONS OF ANY KIND, either express or implied.
 * See the License for the specific language governing permissions and
 * limitations under the License.
 */

#include <SPI.h>
#include <mbed.h>

REDIRECT_STDOUT_TO(Serial);

#include <PluggableUSBHID.h>

#include "srom_3360_0x05.h"
#include "relmouse_16.h"
USBMouse16 mouse(false);

#define REG_PRODUCT_ID (0x00)
#define REG_REVISION_ID (0x01)
#define REG_MOTION (0x02)
#define REG_DELTA_X_L (0x03)
#define REG_DELTA_X_H (0x04)
#define REG_DELTA_Y_L (0x05)
#define REG_DELTA_Y_H (0x06)
#define REG_SQUAL (0x07)
#define REG_RAW_DATA_SUM (0x08)
#define REG_MAX_RAW_DATA (0x09)
#define REG_MIN_RAW_DATA (0x0A)
#define REG_SHUTTER_LOWER (0x0B)
#define REG_SHUTTER_UPPER (0x0C)
#define REG_CONTROL (0x0D)

#define REG_CONFIG1 (0x0F)
#define REG_CONFIG2 (0x10)
#define REG_ANGLE_TUNE (0x11)
#define REG_FRAME_CAPTURE (0x12)
#define REG_SROM_ENABLE (0x13)
#define REG_RUN_DOWNSHIFT (0x14)
#define REG_REST1_RATE_LOWER (0x15)
#define REG_REST1_RATE_UPPER (0x16)
#define REG_REST1_DOWNSHIFT (0x17)
#define REG_REST2_RATE_LOWER (0x18)
#define REG_REST2_RATE_UPPER (0x19)
#define REG_REST2_DOWNSHIFT (0x1A)
#define REG_REST3_RATE_LOWER (0x1B)
#define REG_REST3_RATE_UPPER (0x1C)

#define REG_OBSERVATION (0x24)
#define REG_DATA_OUT_LOWER (0x25)
#define REG_DATA_OUT_UPPER (0x26)

#define REG_RAW_DATA_DUMP (0x29)
#define REG_SROM_ID (0x2A)
#define REG_MIN_SQ_RUN (0x2B)
#define REG_RAW_DATA_THRESHOLD (0x2C)

#define REG_CONFIG5 (0x2F)

#define REG_POWER_UP_RESET (0x3A)
#define REG_SHUTDOWN (0x3B)

#define REG_INVERSE_PRODUCT_ID (0x3F)

#define REG_LIFTCUTOFF_TUNE3 (0x41)
#define REG_ANGLE_SNAP (0x42)

#define REG_LIFTCUTOFF_TUNE1 (0x4A)

#define REG_MOTION_BURST (0x50)

#define REG_LIFTCUTOFF_TUNE_TIMEOUT (0x58)

#define REG_LIFTCUTOFF_TUNE_MIN_LENGTH (0x5A)

#define REG_SROM_LOAD_BURST (0x62)
#define REG_LIFT_CONFIG (0x63)
#define REG_RAW_DATA_BURST (0x64)
#define REG_LIFTOFF_TUNE2 (0x65)

#define CONFIG2_REST_ENABLED (0x30)
#define CONFIG2_REPORT_MODE (0x04)


#define BUTTONS_ON 0
#define BUTTONS_OFF 1

#define BUTTON_M1 2
#define BUTTON_M2 3
#define BUTTON_M3 4
#define BUTTON_M4 6
#define BUTTON_M5 7
#define BUTTON_DPI 5

#define ENCODER_A 8
#define ENCODER_B 10
#define ENCODER_COM 9

#define PIN_NCS 17
#define PIN_MOSI 19
#define PIN_MISO 16

SPISettings spisettings(2000000, MSBFIRST, SPI_MODE3);
MbedSPI spi(PIN_MISO, PIN_MOSI, 18);

void setup_buttons()
{
    pinMode(BUTTONS_OFF, INPUT);
    pinMode(BUTTONS_ON, INPUT);
    pinMode(BUTTON_M1, INPUT_PULLUP);
    pinMode(BUTTON_M2, INPUT_PULLUP);
    pinMode(BUTTON_M3, INPUT_PULLUP);
    pinMode(BUTTON_M4, INPUT_PULLUP);
    pinMode(BUTTON_M5, INPUT_PULLUP);
    pinMode(BUTTON_DPI, INPUT_PULLUP);
    
    pinMode(ENCODER_A, INPUT_PULLUP);
    pinMode(ENCODER_B, INPUT_PULLUP);
    pinMode(ENCODER_COM, OUTPUT);
    
    digitalWrite(ENCODER_COM, LOW);
}

bool mouse_inited;
void setup()
{
    Serial1.begin(1000000);
    
    delay(3000);
    
    // SCK, MISO, MOSI, SS
    SPI.begin();
    pinMode(PIN_NCS, OUTPUT);
    
    digitalWrite(PIN_NCS, HIGH);
    delayMicroseconds(1);
    digitalWrite(PIN_NCS, LOW);
    delayMicroseconds(1);
    digitalWrite(PIN_NCS, HIGH);
    delayMicroseconds(1);
    
    pmw3360_boot();
    
    delay(10);
    
    pmw3360_config();
    
    setup_buttons();
}

uint32_t pins_state = 0;
uint8_t buttons = 0;
uint8_t which_m3 = 0;
// 8ms latch time
uint8_t buttons_latch_max = 8;
uint8_t buttons_latch[5] = {0, 0, 0, 0, 0};

volatile uint32_t * pad_control = (uint32_t *)0x4001c000;
volatile uint32_t * gpio_oe_set = (uint32_t *)0xd0000024;
volatile uint32_t * gpio_oe_clr = (uint32_t *)0xd0000028;
volatile uint32_t * gpio_in = (uint32_t *)0xd0000004;

void update_buttons()
{
    /*
    // disable pullup/pulldown
    pad_control[BUTTONS_OFF + 1] &= 0xFFFFFFF2;
    pad_control[BUTTONS_ON + 1] &= 0xFFFFFFF2;
    */
    
    // change BUTTONS_OFF to high impedance and BUTTONS_ON to output
    // using pinMode for this is way, WAY too slow, like 50us per call (?!?!?!)
    *gpio_oe_clr = 1 << BUTTONS_OFF;
    *gpio_oe_set = 1 << BUTTONS_ON;
    
    // read ON pins
    digitalWrite(BUTTONS_ON, LOW);
    delayMicroseconds(1);
    uint32_t pins_on = ~*gpio_in;
    
    // change BUTTONS_OFF to high impedance and BUTTONS_ON to output
    *gpio_oe_set = 1 << BUTTONS_OFF;
    *gpio_oe_clr = 1 << BUTTONS_ON;
    
    // read OFF pins
    digitalWrite(BUTTONS_OFF, LOW);
    delayMicroseconds(1);
    uint32_t pins_off = ~*gpio_in;
    
    // update pin state
    // treat middle state (on-off matching) as no-update (use previous state)
    uint32_t pins_update = pins_on ^ pins_off;
    pins_state = (pins_state & (~pins_update)) | (pins_on & pins_update);
    
    // update button state
    uint8_t next_buttons =
          ((!!(pins_state & (1 << BUTTON_M1))))
        | ((!!(pins_state & (1 << BUTTON_M2))) << 1)
        | ((!!(pins_state & (1 << BUTTON_M3))) << 2)
        | ((!!(pins_state & (1 << BUTTON_DPI))) << 3)
        | ((!!(pins_state & (1 << BUTTON_M4))) << 4)
        | ((!!(pins_state & (1 << BUTTON_M5))) << 5);
    
    // handle latch
    uint8_t ok_mask = 
          ((buttons_latch[0] == 0))
        | ((buttons_latch[1] == 0) << 1)
        | ((buttons_latch[2] == 0) << 2)
        | ((buttons_latch[3] == 0) << 3)
        | ((buttons_latch[4] == 0) << 4)
        | ((buttons_latch[5] == 0) << 5);
    
    //printf("%u, %u, %u, %u\n", ~pins_on, ~pins_off, pins_state, ok_mask);
    
    next_buttons = (next_buttons & ok_mask) | (buttons & ~ok_mask);
    
    // update latch timings
    for (int i = 0; i < 6; i++)
    {
        if (((next_buttons ^ buttons) >> i) & 1)
            buttons_latch[i] = buttons_latch_max;
        else if (buttons_latch[i])
            buttons_latch[i] -= 1;
    }
    
    if ((next_buttons & (1 << 2)) != (buttons & (1 << 2)))
        which_m3 = 0;
    if ((next_buttons & (1 << 3)) != (buttons & (1 << 3)))
        which_m3 = 1;
    
    buttons = next_buttons;
}

uint8_t wheel_state_a = 0;
uint8_t wheel_state_b = 0;
uint8_t wheel_state_output = 0;
int8_t wheel_progress = 0;

void update_wheel()
{
    uint8_t wheel_new_a = digitalRead(ENCODER_A);
    uint8_t wheel_new_b = digitalRead(ENCODER_B);
    
    if (wheel_new_a != wheel_state_a || wheel_new_b != wheel_state_b)
    {
        if (wheel_new_a == wheel_new_b && wheel_state_output != wheel_new_a)
        {
            // when scrolling up, B changes first. when scrolling down, A changes first
            if (wheel_new_b == wheel_state_b)
                wheel_progress += 1;
            // the wheel can glitch and jump straight from 00 to 11 (or vice versa)
            // so we need to check that only one state has changed since the last test
            else if(wheel_new_a == wheel_state_a)
                wheel_progress -= 1;
            
            wheel_state_output = wheel_new_a;
        }
        
        wheel_state_a = wheel_new_a;
        wheel_state_b = wheel_new_b;
    }
}

int n = 0;
int usb_hid_poll_interval = 1; 

struct MotionBurstData {
    uint8_t motion;
    uint8_t observation;
    int16_t x;
    int16_t y;
    uint8_t squal;
    uint8_t raw_sum;
    uint8_t raw_max;
    uint8_t raw_min;
    uint16_t shutter;
};

MotionBurstData spi_read_motion_burst(bool do_update_wheel);

int dpi = 12; // in hundreds; 1200 dpi
int lod = 2;

void check_config_inputs()
{
    if ((buttons & 1) &&
        (buttons & 2) &&
        (buttons & 8) &&
        (buttons & 16))
    {
        int olddpi = dpi;
        if (wheel_progress < 0)
            dpi += dpi <  16 ? 1 : dpi <  32 ? 2 : dpi <  64 ? 4 : 8;
        else if (wheel_progress > 0)
            dpi -= dpi <= 16 ? 1 : dpi <= 32 ? 2 : dpi <= 64 ? 4 : 8;
        if (dpi > 120)
            dpi = 120;
        else if (dpi < 1)
            dpi = 1;
        
        if (olddpi != dpi)
        {
            spi_write(REG_CONFIG1, dpi - 1);
            
            printf("new DPI: %d\n", dpi * 100);
        }
        
        wheel_progress = 0;
    }
}

void loop()
{
    // these execute nearly instantly
    // we want to call update_wheel roughly every 250ms to avoid skipping
    update_wheel();
    delayMicroseconds(250);
    update_wheel();
    
    int16_t x = 0;
    int16_t y = 0;
    
    // takes ~400us to execute; wheel is updated again around 250ms into the call
    MotionBurstData data = spi_read_motion_burst(true);
    if (mouse_inited && data.motion)
    {
        x = data.x;
        y = data.y;
    }
    
    update_wheel();
    //uint32_t a = micros();
    update_buttons();
    //uint32_t b = micros();
    //Serial.println(b - a);
    
    check_config_inputs();
    
    int8_t wheel = wheel_progress;
    wheel_progress = 0;
    
    //uint32_t a = micros();
    // this will return around 1ms after the last time it returned
    // which should be around 250us from now
    uint8_t new_buttons = buttons;
    if (which_m3)
        new_buttons = (new_buttons & 3) | ((new_buttons >> 1) & ~3);
    else
        new_buttons = (new_buttons & 7) | ((new_buttons >> 1) & ~7);
    mouse.update(x, y, new_buttons, wheel);
    //uint32_t b = micros();
    //Serial.println(b - a);
}

void pmw3360_boot()
{
    spi_write(REG_POWER_UP_RESET, 0x5A);
    delay(50);
    
    spi_read(0x02);
    spi_read(0x03);
    spi_read(0x04);
    spi_read(0x05);
    spi_read(0x06);
    
    srom_upload();
}

void pmw3360_config()
{
    spi_write(REG_CONFIG1, dpi - 1);
}

void spi_begin()
{
    SPI.beginTransaction(spisettings);
}
void spi_end()
{
    SPI.endTransaction();
}

void spi_write(byte addr, byte data)
{
    spi_begin();
    
    digitalWrite(PIN_NCS, LOW);
    delayMicroseconds(1); // 120 nanoseconds; t_NCS-SCLK
    
    SPI.transfer(addr | 0x80);
    SPI.transfer(data);
    
    delayMicroseconds(35); // t_SCLK-NCS(write)
    digitalWrite(PIN_NCS, HIGH);
    
    spi_end();
    
    delayMicroseconds(180); // max(t_SWW, t_SWR)
}

byte spi_read(byte addr)
{
    spi_begin();
    
    digitalWrite(PIN_NCS, LOW);
    delayMicroseconds(1); // 120 nanoseconds; t_NCS-SCLK
    
    SPI.transfer(addr & 0x7F);
    
    delayMicroseconds(160); // t_SRAD
    
    byte ret = SPI.transfer(0);
    
    delayMicroseconds(1); // 120 nanoseconds; t_SCLK-NCS(read)
    digitalWrite(PIN_NCS, HIGH);
    
    spi_end();
    
    delayMicroseconds(20); // max(t_SRW, t_SRR)
    
    return ret;
}

MotionBurstData spi_read_motion_burst(bool do_update_wheel)
{
    MotionBurstData ret = {0};
    
    // this takes around 260us to execute; update scroll wheel again after calling it
    spi_write(REG_MOTION_BURST, 0x00);
    if (do_update_wheel)
        update_wheel();
    
    spi_begin();
    
    digitalWrite(PIN_NCS, LOW);
    delayMicroseconds(1); // 120 nanoseconds; t_NCS-SCLK
    
    SPI.transfer(REG_MOTION_BURST);
    
    delayMicroseconds(35); // t_SRAD_MOTBR
    
    ret.motion = SPI.transfer(0);
    ret.observation = SPI.transfer(0);
    ret.x = SPI.transfer(0);
    ret.x |= ((uint16_t)SPI.transfer(0)) << 8;
    ret.y = SPI.transfer(0);
    ret.y |= ((uint16_t)SPI.transfer(0)) << 8;
    ret.squal = SPI.transfer(0);
    // don't care about the rest; terminate
    digitalWrite(PIN_NCS, HIGH);
    delayMicroseconds(1); // t_BEXIT = 500ns; wait 1000ns (1us)
    
    /*
    ret.raw_sum = SPI.transfer(0);
    ret.raw_max = SPI.transfer(0);
    ret.raw_min = SPI.transfer(0);
    ret.shutter = SPI.transfer(0);
    ret.shutter |= ((uint16_t)SPI.transfer(0)) << 8;
    */
    
    spi_end();
    
    return ret;
}

void srom_upload()
{
    spi_write(REG_CONFIG2, 0x00);
    spi_write(REG_SROM_ENABLE, 0x1D);
    delay(10);
    
    spi_write(REG_SROM_ENABLE, 0x18);
    
    spi_begin();
    
    digitalWrite(PIN_NCS, LOW);
    delayMicroseconds(1);
    
    SPI.transfer(REG_SROM_LOAD_BURST | 0x80);
    delayMicroseconds(15);
    
    for(size_t i = 0; i < SROM_LENGTH; i += 1)
    {
        SPI.transfer(srom[i]);
        delayMicroseconds(15);
    }
    
    digitalWrite(PIN_NCS, HIGH);
    delayMicroseconds(1);
    
    spi_end();
    
    delayMicroseconds(200);
    
    byte id = spi_read(REG_SROM_ID);
    mouse_inited = (id != 0xFF);
    printf("\n");
    printf("srom id: ");
    printf("%d", id);
    printf("\n");
    
    spi_write(REG_CONFIG2, 0x00);
}

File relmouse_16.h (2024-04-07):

/*
 * Copyright (c) 2018-2019, Arm Limited and affiliates.
 * SPDX-License-Identifier: Apache-2.0
 *
 * Licensed under the Apache License, Version 2.0 (the "License");
 * you may not use this file except in compliance with the License.
 * You may obtain a copy of the License at
 *
 *     http://www.apache.org/licenses/LICENSE-2.0
 *
 * Unless required by applicable law or agreed to in writing, software
 * distributed under the License is distributed on an "AS IS" BASIS,
 * WITHOUT WARRANTIES OR CONDITIONS OF ANY KIND, either express or implied.
 * See the License for the specific language governing permissions and
 * limitations under the License.
 */

// from https://github.com/arduino/ArduinoCore-mbed
// modified: header and source file combined
// modified: docs removed for brevity
// modified: made 16-bit

#include "USBHID.h"
#include "PlatformMutex.h"

#define REPORT_ID_MOUSE   2

#define X_MIN_REL    (-32767)
#define Y_MIN_REL    (-32767)
#define X_MAX_REL    (32767)
#define Y_MAX_REL    (32767)

class USBMouse16: public USBHID {
public:
    USBMouse16(bool connect_blocking = true, uint16_t vendor_id = 0x8234, uint16_t product_id = 0x0001, uint16_t product_release = 0x0001);

    USBMouse16(USBPhy *phy, uint16_t vendor_id = 0x8234, uint16_t product_id = 0x0001, uint16_t product_release = 0x0001);

    virtual ~USBMouse16();

    bool update(int16_t x, int16_t y, uint8_t buttons, int8_t z);
    
    virtual const uint8_t *report_desc();

protected:
    virtual const uint8_t *configuration_desc(uint8_t index);

private:
    uint8_t _configuration_descriptor[41];
    PlatformMutex _mutex;

};

#include "stdint.h"
#include "ThisThread.h"
#include "usb_phy_api.h"

using namespace arduino;
using namespace std::chrono_literals;

USBMouse16::USBMouse16(bool connect_blocking, uint16_t vendor_id, uint16_t product_id, uint16_t product_release):
    USBHID(get_usb_phy(), 0, 0, vendor_id, product_id, product_release)
{
}

USBMouse16::USBMouse16(USBPhy *phy, uint16_t vendor_id, uint16_t product_id, uint16_t product_release):
    USBHID(get_usb_phy(), 0, 0, vendor_id, product_id, product_release)
{
}

USBMouse16::~USBMouse16()
{
}

bool USBMouse16::update(int16_t x, int16_t y, uint8_t buttons, int8_t z)
{
    _mutex.lock();

    HID_REPORT report;
    report.data[0] = buttons;
    report.data[1] = (uint8_t)(x);
    report.data[2] = (uint8_t)(((uint16_t)x) >> 8);
    report.data[3] = (uint8_t)(y);
    report.data[4] = (uint8_t)(((uint16_t)y) >> 8);
    report.data[5] = -z; // >0 to scroll down, <0 to scroll up

    report.length = 6;

    bool ret = send(&report);

    _mutex.unlock();
    return ret;
}

const uint8_t *USBMouse16::report_desc()
{
    static const uint8_t report_descriptor[] = {
        USAGE_PAGE(1),      0x01,       // Genric Desktop
        USAGE(1),           0x02,       // Mouse
        COLLECTION(1),      0x01,       // Application
        USAGE(1),           0x01,       // Pointer
        COLLECTION(1),      0x00,       // Physical

        // Buttons
        REPORT_COUNT(1),    0x05,
        REPORT_SIZE(1),     0x01,
        USAGE_PAGE(1),      0x09,
        USAGE_MINIMUM(1),       0x01,
        USAGE_MAXIMUM(1),       0x05,
        LOGICAL_MINIMUM(1),     0x00,
        LOGICAL_MAXIMUM(1),     0x01,
        INPUT(1),           0x02,
        // Padding
        REPORT_COUNT(1),    0x01,
        REPORT_SIZE(1),     0x03,
        INPUT(1),           0x01,

        REPORT_COUNT(1),    2,
        REPORT_SIZE(1),     16,
        USAGE_PAGE(1),      1,
        USAGE(1),           0x30,       // X
        USAGE(1),           0x31,       // Y
        LOGICAL_MINIMUM(2),     0x01, 0x80,
        LOGICAL_MAXIMUM(2),     0xff, 0x7f,
        INPUT(1),           0x06,       // Relative data
        
        REPORT_COUNT(1),    1,
        REPORT_SIZE(1),     8,
        USAGE_PAGE(1),      1,
        USAGE(1),           0x38,       // scroll
        LOGICAL_MINIMUM(1),     0x81,
        LOGICAL_MAXIMUM(1),     0x7f,
        INPUT(1),           0x06,       // Relative data

        END_COLLECTION(0),
        END_COLLECTION(0),
    };
    reportLength = sizeof(report_descriptor);
    return report_descriptor;
}

#define DEFAULT_CONFIGURATION (1)
#define TOTAL_DESCRIPTOR_LENGTH ((1 * CONFIGURATION_DESCRIPTOR_LENGTH) \
                               + (1 * INTERFACE_DESCRIPTOR_LENGTH) \
                               + (1 * HID_DESCRIPTOR_LENGTH) \
                               + (2 * ENDPOINT_DESCRIPTOR_LENGTH))

const uint8_t *USBMouse16::configuration_desc(uint8_t index)
{
    if (index != 0) {
        return NULL;
    }
    uint8_t configuration_descriptor_temp[] = {
        CONFIGURATION_DESCRIPTOR_LENGTH,    // bLength
        CONFIGURATION_DESCRIPTOR,           // bDescriptorType
        LSB(TOTAL_DESCRIPTOR_LENGTH),       // wTotalLength (LSB)
        MSB(TOTAL_DESCRIPTOR_LENGTH),       // wTotalLength (MSB)
        0x01,                               // bNumInterfaces
        DEFAULT_CONFIGURATION,              // bConfigurationValue
        0x00,                               // iConfiguration
        C_RESERVED | C_SELF_POWERED,        // bmAttributes
        C_POWER(0),                         // bMaxPower

        INTERFACE_DESCRIPTOR_LENGTH,        // bLength
        INTERFACE_DESCRIPTOR,               // bDescriptorType
        0x00,                               // bInterfaceNumber
        0x00,                               // bAlternateSetting
        0x02,                               // bNumEndpoints
        HID_CLASS,                          // bInterfaceClass
        HID_SUBCLASS_BOOT,                  // bInterfaceSubClass
        HID_PROTOCOL_MOUSE,                 // bInterfaceProtocol
        0x00,                               // iInterface

        HID_DESCRIPTOR_LENGTH,              // bLength
        HID_DESCRIPTOR,                     // bDescriptorType
        LSB(HID_VERSION_1_11),              // bcdHID (LSB)
        MSB(HID_VERSION_1_11),              // bcdHID (MSB)
        0x00,                               // bCountryCode
        0x01,                               // bNumDescriptors
        REPORT_DESCRIPTOR,                  // bDescriptorType
        (uint8_t)(LSB(report_desc_length())), // wDescriptorLength (LSB)
        (uint8_t)(MSB(report_desc_length())), // wDescriptorLength (MSB)

        ENDPOINT_DESCRIPTOR_LENGTH,         // bLength
        ENDPOINT_DESCRIPTOR,                // bDescriptorType
        _int_in,                            // bEndpointAddress
        E_INTERRUPT,                        // bmAttributes
        LSB(MAX_HID_REPORT_SIZE),           // wMaxPacketSize (LSB)
        MSB(MAX_HID_REPORT_SIZE),           // wMaxPacketSize (MSB)
        1,                                  // bInterval (milliseconds)
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

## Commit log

2024-04-08 update scroll wheel model to fit better in the encoder
    [mouse shell progress pico 2 wheel.stl]
2024-04-09 change wheel updates to hardcoded checkpoints in main loop instead of interrupt timer; might improve stability (I hope)
    [3360_Mouse_pico.ino]
2024-11-24 disable tracking if sensor is disconnected
2024-11-24 fix bug where a stuck m3 or dpi button would block the other from working
    [3360_Mouse_pico.ino]
